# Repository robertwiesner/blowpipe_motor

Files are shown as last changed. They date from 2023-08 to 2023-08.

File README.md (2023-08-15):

# Glassblowing adapter

This project is to build a blow pipe adapter to help with solo blowing. In contras to the external compressor to the blowpie using a hose. 
The goals include
* Identic PCB for blowpipe and wireless controller
* Easy configurable
* Using Wifi or Bluetooth as communication between the remote control and blow piep adapter
* Measuring the set and create air pressure
* Worktime at last 4 hours on one charge
* Reasonable cost effective

I'm using a Rasperry Pi Pico W running Micropython.

The repository contains
* Schematics for the PCB
* FreeCAD 0.21 models with easy adjustments for the adapter and remote control

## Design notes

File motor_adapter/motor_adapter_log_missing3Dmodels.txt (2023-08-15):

Can not find model defined with enviroment variable:
${KICAD6_3DMODEL_USER_DIR}/RPi Pico W w_headers.step
Can not find model defined with enviroment variable:
${KICAD6_3DMODEL_DIR}/LED_SMD.3dshapes/LED_0603_1608Metric.wrl
Can not find model defined with enviroment variable:
${KICAD6_3DMODEL_DIR}/Resistor_SMD.3dshapes/R_0402_1005Metric.wrl
Can not find model defined with enviroment variable:
${KICAD6_3DMODEL_DIR}/Capacitor_Tantalum_SMD.3dshapes/CP_EIA-7343-31_Kemet-D.wrl
Can not find model defined with enviroment variable:
${KICAD6_3DMODEL_DIR}/Inductor_SMD.3dshapes/L_0603_1608Metric.wrl
Can not find model defined with enviroment variable:
${KICAD6_3DMODEL_DIR}/LED_SMD.3dshapes/LED_0603_1608Metric.wrl
Can not find model defined with enviroment variable:
${KICAD6_3DMODEL_DIR}/Resistor_SMD.3dshapes/R_0402_1005Metric.wrl
Can not find model defined with enviroment variable:
${KICAD6_3DMODEL_DIR}/Capacitor_SMD.3dshapes/C_0603_1608Metric.wrl
Can not find model defined with enviroment variable:
${KICAD6_3DMODEL_DIR}/Package_TO_SOT_SMD.3dshapes/SOT-223.wrl
Can not find model defined with enviroment variable:
${KICAD6_3DMODEL_DIR}/Capacitor_SMD.3dshapes/C_0402_1005Metric.wrl
Can not find model defined with enviroment variable:
${KICAD6_3DMODEL_DIR}/Capacitor_SMD.3dshapes/C_0402_1005Metric.wrl
Can not find model defined with enviroment variable:
${KICAD6_3DMODEL_DIR}/Resistor_SMD.3dshapes/R_0402_1005Metric.wrl
Can not find model defined with enviroment variable:
${KICAD6_3DMODEL_DIR}/Capacitor_SMD.3dshapes/CP_Elec_10x10.5.wrl
Can not find model defined with enviroment variable:
${KICAD6_3DMODEL_DIR}/Package_TO_SOT_SMD.3dshapes/TO-263-5_TabPin6.wrl
Can not find model defined with enviroment variable:
${KICAD6_3DMODEL_DIR}/Resistor_SMD.3dshapes/R_0402_1005Metric.wrl
Can not find model defined with enviroment variable:
${KICAD6_3DMODEL_DIR}/Capacitor_SMD.3dshapes/C_0402_1005Metric.wrl
Can not find model defined with enviroment variable:
${KICAD6_3DMODEL_DIR}/Capacitor_SMD.3dshapes/C_0603_1608Metric.wrl
Can not find model defined with enviroment variable:
${KICAD6_3DMODEL_DIR}/Capacitor_Tantalum_SMD.3dshapes/CP_EIA-3216-18_Kemet-A.wrl
Can not find model defined with enviroment variable:
${KICAD6_3DMODEL_DIR}/Capacitor_SMD.3dshapes/C_0402_1005Metric.wrl
Can not find model defined with enviroment variable:
${KICAD6_3DMODEL_DIR}/Capacitor_Tantalum_SMD.3dshapes/CP_EIA-3216-18_Kemet-A.wrl
Can not find model defined with enviroment variable:
${KICAD6_3DMODEL_DIR}/Connector_PinSocket_2.54mm.3dshapes/PinSocket_1x04_P2.54mm_Vertical.wrl
Can not find model defined with enviroment variable:
${KICAD6_3DMODEL_DIR}/Capacitor_SMD.3dshapes/C_0603_1608Metric.wrl
Can not find model defined with enviroment variable:
${KICAD6_3DMODEL_DIR}/Capacitor_SMD.3dshapes/C_0402_1005Metric.wrl
Can not find model defined with enviroment variable:
${KICAD6_3DMODEL_DIR}/Package_SO.3dshapes/TSSOP-10_3x3mm_P0.5mm.wrl
Can not find model defined with enviroment variable:
${KICAD6_3DMODEL_DIR}/Inductor_SMD.3dshapes/L_Bourns_SRP7028A_7.3x6.6mm.wrl
Can not find model defined with enviroment variable:
${KICAD6_3DMODEL_DIR}/Resistor_SMD.3dshapes/R_0402_1005Metric.wrl
Can not find model defined with enviroment variable:
${KICAD6_3DMODEL_DIR}/LED_SMD.3dshapes/LED_0603_1608Metric.wrl
Can not find model defined with enviroment variable:
${KICAD6_3DMODEL_DIR}/Capacitor_SMD.3dshapes/C_0402_1005Metric.wrl
Can not find model defined with enviroment variable:
${KICAD6_3DMODEL_DIR}/Connector_PinHeader_2.54mm.3dshapes/PinHeader_1x02_P2.54mm_Vertical.wrl
Can not find model defined with enviroment variable:
${KICAD6_3DMODEL_DIR}/Resistor_SMD.3dshapes/R_0402_1005Metric.wrl
Can not find model defined with enviroment variable:
${KICAD6_3DMODEL_DIR}/Button_Switch_SMD.3dshapes/SW_DIP_SPSTx04_Slide_Copal_CHS-04B_W7.62mm_P1.27mm.wrl
Can not find model defined with enviroment variable:
${KICAD6_3DMODEL_DIR}/Capacitor_SMD.3dshapes/C_0603_1608Metric.wrl
Can not find model defined with enviroment variable:
${KICAD6_3DMODEL_DIR}/Connector_PinHeader_2.54mm.3dshapes/PinHeader_1x05_P2.54mm_Vertical.wrl
Can not find model defined with enviroment variable:
${KICAD6_3DMODEL_DIR}/LED_SMD.3dshapes/LED_0603_1608Metric.wrl
Can not find model defined with enviroment variable:
${KICAD6_3DMODEL_DIR}/Capacitor_SMD.3dshapes/C_0402_1005Metric.wrl
Can not find model defined with enviroment variable:
${KICAD6_3DMODEL_DIR}/Connector_PinHeader_2.54mm.3dshapes/PinHeader_1x03_P2.54mm_Vertical.wrl
Can not find model defined with enviroment variable:
${KICAD6_3DMODEL_DIR}/Resistor_SMD.3dshapes/R_0402_1005Metric.wrl
Can not find model defined with enviroment variable:
${KICAD6_3DMODEL_DIR}/Resistor_SMD.3dshapes/R_0402_1005Metric.wrl
Can not find model defined with enviroment variable:
${KICAD6_3DMODEL_DIR}/Resistor_SMD.3dshapes/R_0402_1005Metric.wrl
Can not find model defined with enviroment variable:
${KICAD6_3DMODEL_DIR}/Inductor_SMD.3dshapes/L_Bourns_SRP7028A_7.3x6.6mm.wrl
[('A101', '${KICAD6_3DMODEL_USER_DIR}/RPi Pico W w_headers.step'), ('D404', '${KICAD6_3DMODEL_DIR}/LED_SMD.3dshapes/LED_0603_1608Metric.wrl'), ('R503', '${KICAD6_3DMODEL_DIR}/Resistor_SMD.3dshapes/R_0402_1005Metric.wrl'), ('C302', '${KICAD6_3DMODEL_DIR}/Capacitor_Tantalum_SMD.3dshapes/CP_EIA-7343-31_Kemet-D.wrl'), ('FB301', '${KICAD6_3DMODEL_DIR}/Inductor_SMD.3dshapes/L_0603_1608Metric.wrl'), ('D403', '${KICAD6_3DMODEL_DIR}/LED_SMD.3dshapes/LED_0603_1608Metric.wrl'), ('R501', '${KICAD6_3DMODEL_DIR}/Resistor_SMD.3dshapes/R_0402_1005Metric.wrl'), ('C305', '${KICAD6_3DMODEL_DIR}/Capacitor_SMD.3dshapes/C_0603_1608Metric.wrl'), ('U302', '${KICAD6_3DMODEL_DIR}/Package_TO_SOT_SMD.3dshapes/SOT-223.wrl'), ('C402', '${KICAD6_3DMODEL_DIR}/Capacitor_SMD.3dshapes/C_0402_1005Metric.wrl'), ('C201', '${KICAD6_3DMODEL_DIR}/Capacitor_SMD.3dshapes/C_0402_1005Metric.wrl'), ('R404', '${KICAD6_3DMODEL_DIR}/Resistor_SMD.3dshapes/R_0402_1005Metric.wrl'), ('C301', '${KICAD6_3DMODEL_DIR}/Capacitor_SMD.3dshapes/CP_Elec_10x10.5.wrl'), ('U301', '${KICAD6_3DMODEL_DIR}/Package_TO_SOT_SMD.3dshapes/TO-263-5_TabPin6.wrl'), ('R502', '${KICAD6_3DMODEL_DIR}/Resistor_SMD.3dshapes/R_0402_1005Metric.wrl'), ('C401', '${KICAD6_3DMODEL_DIR}/Capacitor_SMD.3dshapes/C_0402_1005Metric.wrl'), ('C306', '${KICAD6_3DMODEL_DIR}/Capacitor_SMD.3dshapes/C_0603_1608Metric.wrl'), ('C403', '${KICAD6_3DMODEL_DIR}/Capacitor_Tantalum_SMD.3dshapes/CP_EIA-3216-18_Kemet-A.wrl'), ('C307', '${KICAD6_3DMODEL_DIR}/Capacitor_SMD.3dshapes/C_0402_1005Metric.wrl'), ('C404', '${KICAD6_3DMODEL_DIR}/Capacitor_Tantalum_SMD.3dshapes/CP_EIA-3216-18_Kemet-A.wrl'), ('J102', '${KICAD6_3DMODEL_DIR}/Connector_PinSocket_2.54mm.3dshapes/PinSocket_1x04_P2.54mm_Vertical.wrl'), ('C303', '${KICAD6_3DMODEL_DIR}/Capacitor_SMD.3dshapes/C_0603_1608Metric.wrl'), ('C501', '${KICAD6_3DMODEL_DIR}/Capacitor_SMD.3dshapes/C_0402_1005Metric.wrl'), ('U501', '${KICAD6_3DMODEL_DIR}/Package_SO.3dshapes/TSSOP-10_3x3mm_P0.5mm.wrl'), ('L301', '${KICAD6_3DMODEL_DIR}/Inductor_SMD.3dshapes/L_Bourns_SRP7028A_7.3x6.6mm.wrl'), ('R101', '${KICAD6_3DMODEL_DIR}/Resistor_SMD.3dshapes/R_0402_1005Metric.wrl'), ('D402', '${KICAD6_3DMODEL_DIR}/LED_SMD.3dshapes/LED_0603_1608Metric.wrl'), ('C308', '${KICAD6_3DMODEL_DIR}/Capacitor_SMD.3dshapes/C_0402_1005Metric.wrl'), ('J302', '${KICAD6_3DMODEL_DIR}/Connector_PinHeader_2.54mm.3dshapes/PinHeader_1x02_P2.54mm_Vertical.wrl'), ('R403', '${KICAD6_3DMODEL_DIR}/Resistor_SMD.3dshapes/R_0402_1005Metric.wrl'), ('SW101', '${KICAD6_3DMODEL_DIR}/Button_Switch_SMD.3dshapes/SW_DIP_SPSTx04_Slide_Copal_CHS-04B_W7.62mm_P1.27mm.wrl'), ('C304', '${KICAD6_3DMODEL_DIR}/Capacitor_SMD.3dshapes/C_0603_1608Metric.wrl'), ('J101', '${KICAD6_3DMODEL_DIR}/Connector_PinHeader_2.54mm.3dshapes/PinHeader_1x05_P2.54mm_Vertical.wrl'), ('D401', '${KICAD6_3DMODEL_DIR}/LED_SMD.3dshapes/LED_0603_1608Metric.wrl'), ('C309', '${KICAD6_3DMODEL_DIR}/Capacitor_SMD.3dshapes/C_0402_1005Metric.wrl'), ('J402', '${KICAD6_3DMODEL_DIR}/Connector_PinHeader_2.54mm.3dshapes/PinHeader_1x03_P2.54mm_Vertical.wrl'), ('R402', '${KICAD6_3DMODEL_DIR}/Resistor_SMD.3dshapes/R_0402_1005Metric.wrl'), ('R401', '${KICAD6_3DMODEL_DIR}/Resistor_SMD.3dshapes/R_0402_1005Metric.wrl'), ('R102', '${KICAD6_3DMODEL_DIR}/Resistor_SMD.3dshapes/R_0402_1005Metric.wrl'), ('L302', '${KICAD6_3DMODEL_DIR}/Inductor_SMD.3dshapes/L_Bourns_SRP7028A_7.3x6.6mm.wrl')]

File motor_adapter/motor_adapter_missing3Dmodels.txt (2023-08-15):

### Missing 3D models - created on 2023-07-03 17:45
### Printed by checking_3D_models plugin
Board file: /home/robert/kicad/motor_adapter/motor_adapter.kicad_pcb
3D missing models written to:
/home/robert/kicad/motor_adapter/motor_adapter_missing3Dmodels.txt
-------
('A101', '${KICAD6_3DMODEL_USER_DIR}/RPi Pico W w_headers.step')
('D404', '${KICAD6_3DMODEL_DIR}/LED_SMD.3dshapes/LED_0603_1608Metric.wrl')
('R503', '${KICAD6_3DMODEL_DIR}/Resistor_SMD.3dshapes/R_0402_1005Metric.wrl')
('C302', '${KICAD6_3DMODEL_DIR}/Capacitor_Tantalum_SMD.3dshapes/CP_EIA-7343-31_Kemet-D.wrl')
('FB301', '${KICAD6_3DMODEL_DIR}/Inductor_SMD.3dshapes/L_0603_1608Metric.wrl')
('D403', '${KICAD6_3DMODEL_DIR}/LED_SMD.3dshapes/LED_0603_1608Metric.wrl')
('R501', '${KICAD6_3DMODEL_DIR}/Resistor_SMD.3dshapes/R_0402_1005Metric.wrl')
('C305', '${KICAD6_3DMODEL_DIR}/Capacitor_SMD.3dshapes/C_0603_1608Metric.wrl')
('U302', '${KICAD6_3DMODEL_DIR}/Package_TO_SOT_SMD.3dshapes/SOT-223.wrl')
('C402', '${KICAD6_3DMODEL_DIR}/Capacitor_SMD.3dshapes/C_0402_1005Metric.wrl')
('C201', '${KICAD6_3DMODEL_DIR}/Capacitor_SMD.3dshapes/C_0402_1005Metric.wrl')
('R404', '${KICAD6_3DMODEL_DIR}/Resistor_SMD.3dshapes/R_0402_1005Metric.wrl')
('C301', '${KICAD6_3DMODEL_DIR}/Capacitor_SMD.3dshapes/CP_Elec_10x10.5.wrl')
('U301', '${KICAD6_3DMODEL_DIR}/Package_TO_SOT_SMD.3dshapes/TO-263-5_TabPin6.wrl')
('R502', '${KICAD6_3DMODEL_DIR}/Resistor_SMD.3dshapes/R_0402_1005Metric.wrl')
('C401', '${KICAD6_3DMODEL_DIR}/Capacitor_SMD.3dshapes/C_0402_1005Metric.wrl')
('C306', '${KICAD6_3DMODEL_DIR}/Capacitor_SMD.3dshapes/C_0603_1608Metric.wrl')
('C403', '${KICAD6_3DMODEL_DIR}/Capacitor_Tantalum_SMD.3dshapes/CP_EIA-3216-18_Kemet-A.wrl')
('C307', '${KICAD6_3DMODEL_DIR}/Capacitor_SMD.3dshapes/C_0402_1005Metric.wrl')
('C404', '${KICAD6_3DMODEL_DIR}/Capacitor_Tantalum_SMD.3dshapes/CP_EIA-3216-18_Kemet-A.wrl')
('J102', '${KICAD6_3DMODEL_DIR}/Connector_PinSocket_2.54mm.3dshapes/PinSocket_1x04_P2.54mm_Vertical.wrl')
('C303', '${KICAD6_3DMODEL_DIR}/Capacitor_SMD.3dshapes/C_0603_1608Metric.wrl')
('C501', '${KICAD6_3DMODEL_DIR}/Capacitor_SMD.3dshapes/C_0402_1005Metric.wrl')
('U501', '${KICAD6_3DMODEL_DIR}/Package_SO.3dshapes/TSSOP-10_3x3mm_P0.5mm.wrl')
('L301', '${KICAD6_3DMODEL_DIR}/Inductor_SMD.3dshapes/L_Bourns_SRP7028A_7.3x6.6mm.wrl')
('R101', '${KICAD6_3DMODEL_DIR}/Resistor_SMD.3dshapes/R_0402_1005Metric.wrl')
('D402', '${KICAD6_3DMODEL_DIR}/LED_SMD.3dshapes/LED_0603_1608Metric.wrl')
('C308', '${KICAD6_3DMODEL_DIR}/Capacitor_SMD.3dshapes/C_0402_1005Metric.wrl')
('J302', '${KICAD6_3DMODEL_DIR}/Connector_PinHeader_2.54mm.3dshapes/PinHeader_1x02_P2.54mm_Vertical.wrl')
('R403', '${KICAD6_3DMODEL_DIR}/Resistor_SMD.3dshapes/R_0402_1005Metric.wrl')
('SW101', '${KICAD6_3DMODEL_DIR}/Button_Switch_SMD.3dshapes/SW_DIP_SPSTx04_Slide_Copal_CHS-04B_W7.62mm_P1.27mm.wrl')
('C304', '${KICAD6_3DMODEL_DIR}/Capacitor_SMD.3dshapes/C_0603_1608Metric.wrl')
('J101', '${KICAD6_3DMODEL_DIR}/Connector_PinHeader_2.54mm.3dshapes/PinHeader_1x05_P2.54mm_Vertical.wrl')
('D401', '${KICAD6_3DMODEL_DIR}/LED_SMD.3dshapes/LED_0603_1608Metric.wrl')
('C309', '${KICAD6_3DMODEL_DIR}/Capacitor_SMD.3dshapes/C_0402_1005Metric.wrl')
('J402', '${KICAD6_3DMODEL_DIR}/Connector_PinHeader_2.54mm.3dshapes/PinHeader_1x03_P2.54mm_Vertical.wrl')
('R402', '${KICAD6_3DMODEL_DIR}/Resistor_SMD.3dshapes/R_0402_1005Metric.wrl')
('R401', '${KICAD6_3DMODEL_DIR}/Resistor_SMD.3dshapes/R_0402_1005Metric.wrl')
('R102', '${KICAD6_3DMODEL_DIR}/Resistor_SMD.3dshapes/R_0402_1005Metric.wrl')
('L302', '${KICAD6_3DMODEL_DIR}/Inductor_SMD.3dshapes/L_Bourns_SRP7028A_7.3x6.6mm.wrl')
-------
NUM of 3D missing models:40
checked extensions ['.stp', '.step', '.stpZ']

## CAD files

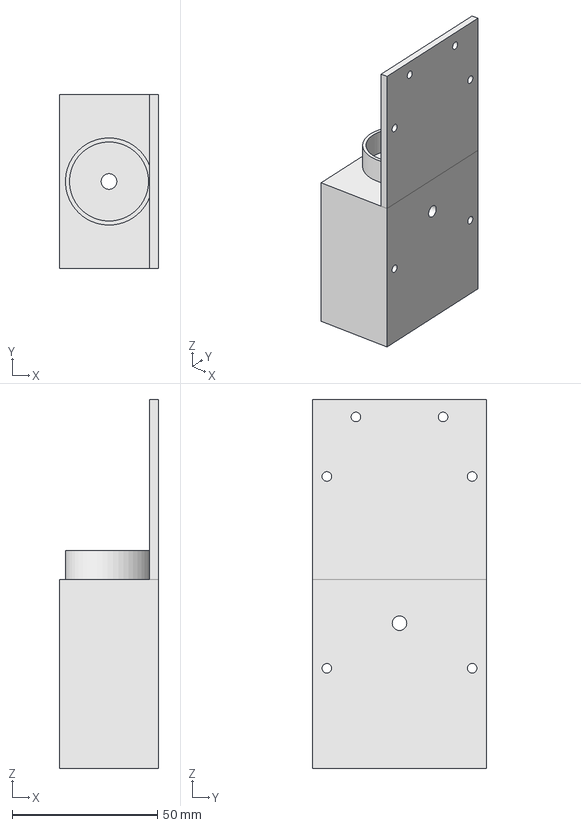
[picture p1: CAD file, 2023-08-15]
freecad/blowpipe_adapter.FCStd
34.0 x 60.0 x 127.0 mm

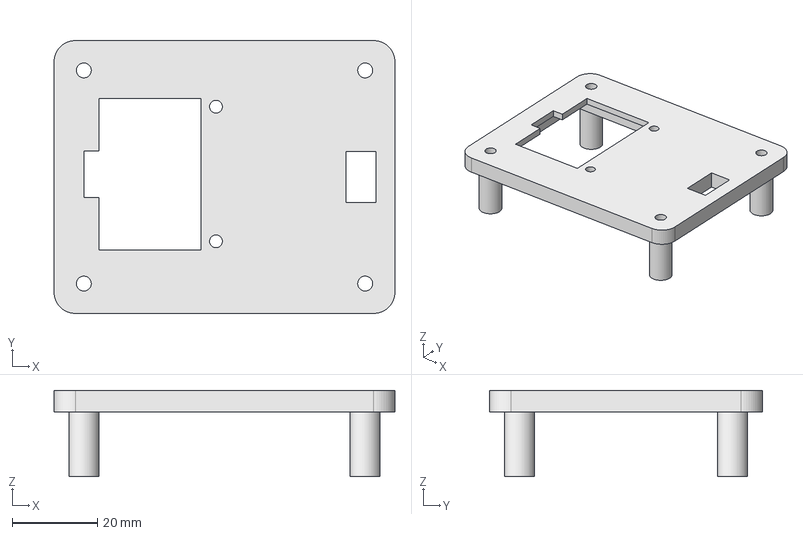
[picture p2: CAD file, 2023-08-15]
freecad/pcb_box_top.FCStd
80.0 x 64.0 x 20.2 mm

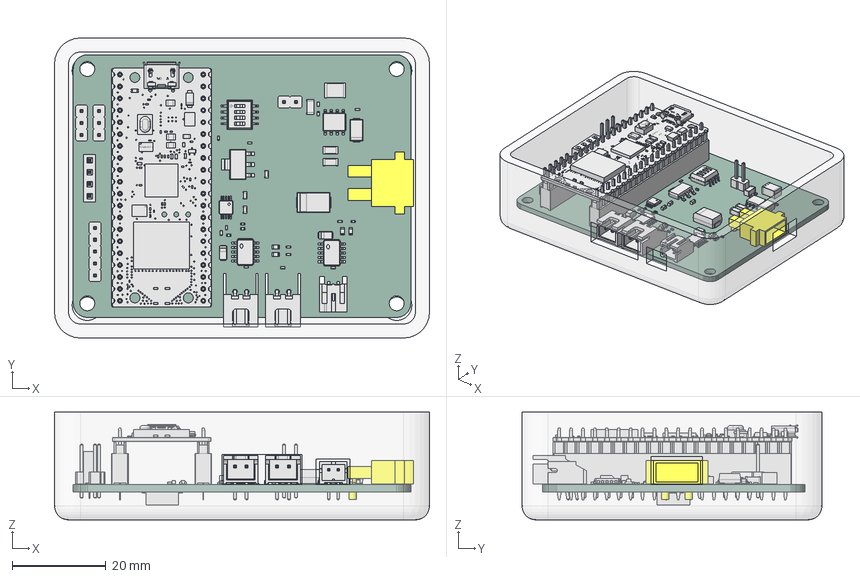
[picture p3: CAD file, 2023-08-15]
freecad/pcb_box.FCStd
80.0 x 64.0 x 23.0 mm
_autosave-motor_adapter PCB

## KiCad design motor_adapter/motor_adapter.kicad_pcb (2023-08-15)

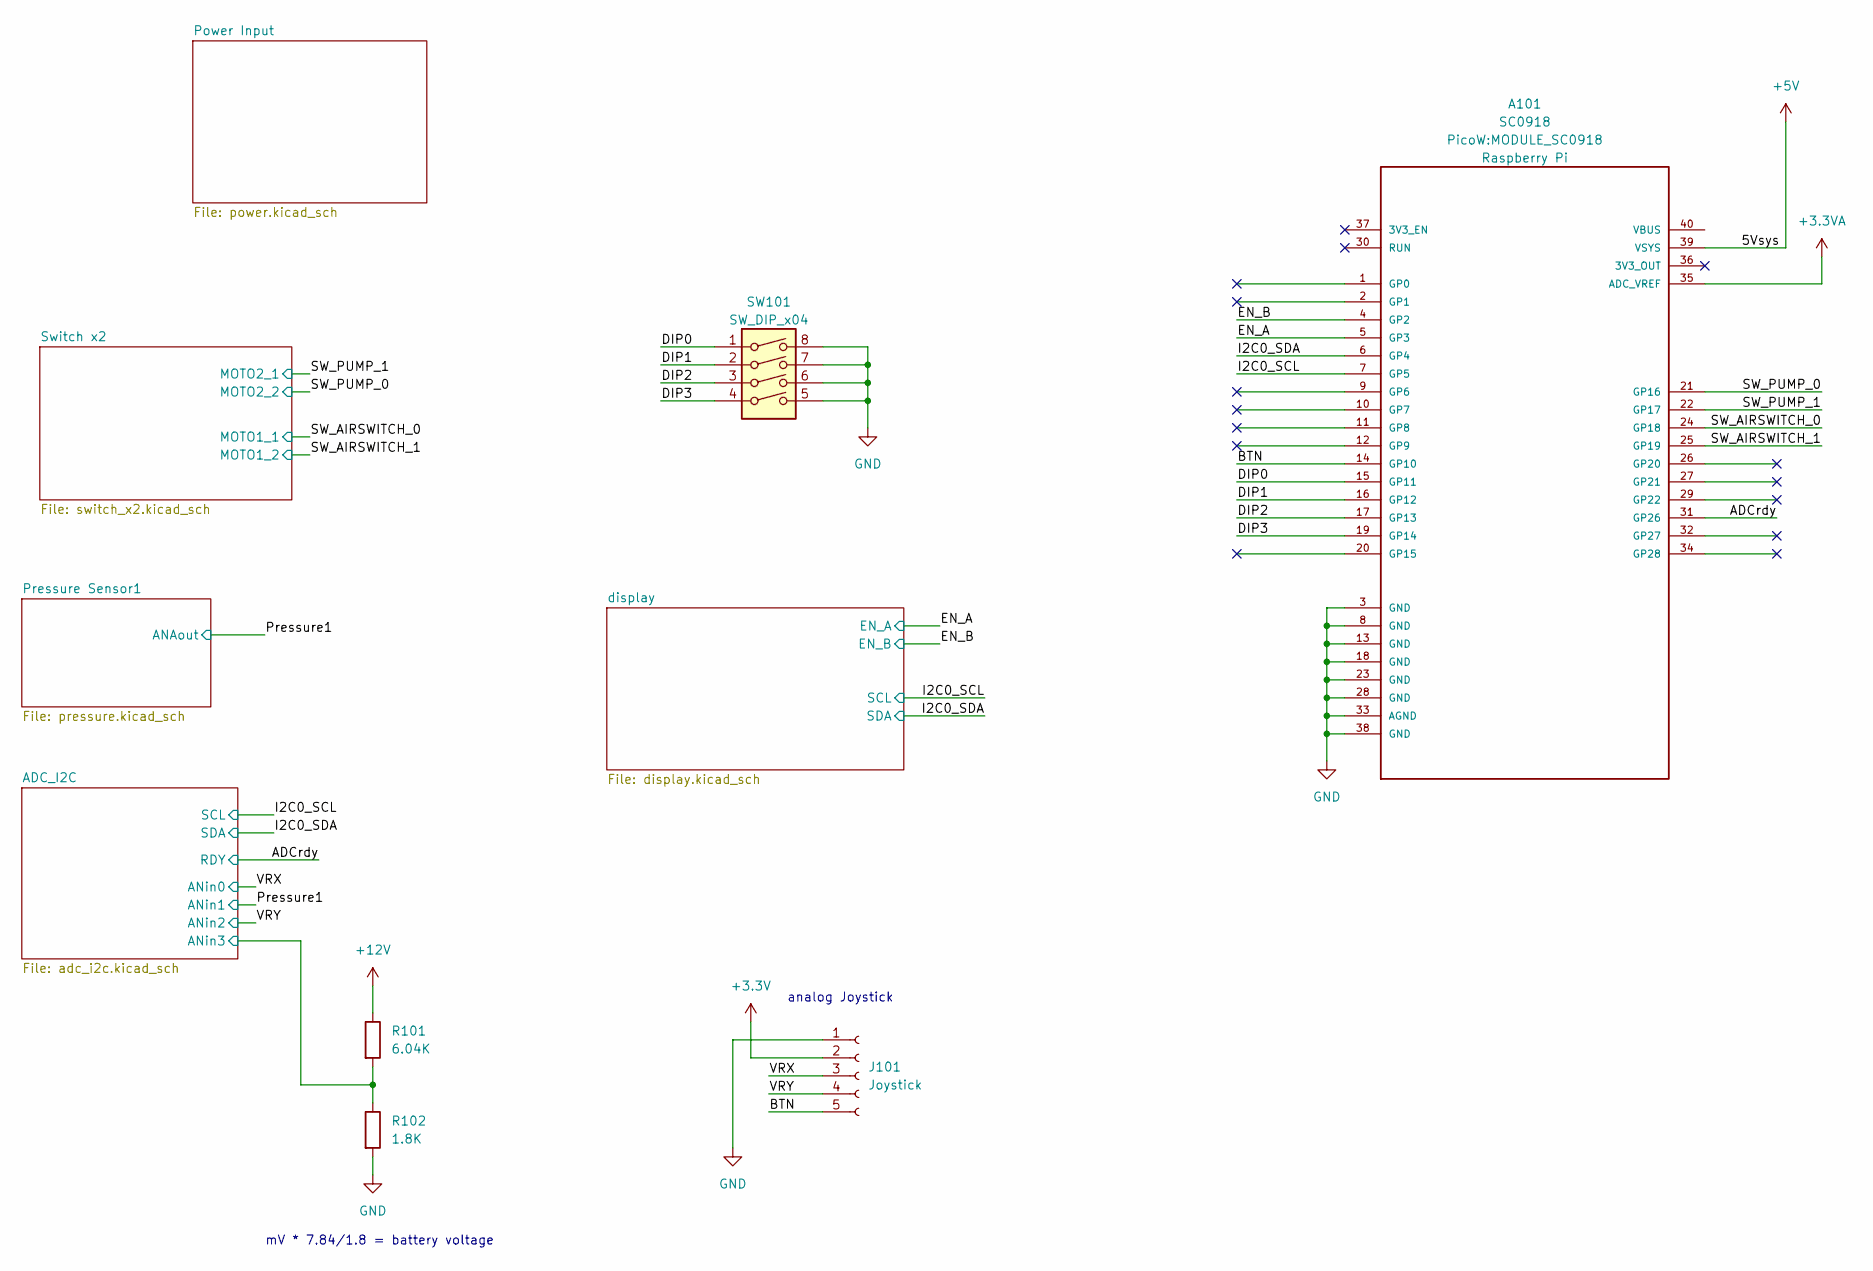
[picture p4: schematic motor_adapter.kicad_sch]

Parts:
A101: SC0918; MODULE_SC0918; PARTREV 1.6
J101: Joystick; PinHeader_1x05_P2.54mm_Vertical
R101: 6.04K; R_0402_1005Metric; Part 0402WGF2001TCE; LCSC C852895
R102: 1.8K; R_0402_1005Metric; Part 0402WGF2001TCE; LCSC C852621
SW101: SW_DIP_x04; SW_DIP_SPSTx04_Slide_Copal_CHS-04B_W7.62mm_P1.27mm; LCSC C845385

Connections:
+3.3V: J101.2; also elsewhere on the board
+3.3VA: A101.35 (ADC_VREF); also elsewhere on the board
/ADC_I2C/ANin3: R101.2, R102.1; also elsewhere on the board
/ADCrdy: A101.31 (GP26); also elsewhere on the board
/BTN: A101.14 (GP10), J101.5
/DIP0: A101.15 (GP11), SW101.1
/DIP1: A101.16 (GP12), SW101.2
/DIP2: A101.17 (GP13), SW101.3
/DIP3: A101.19 (GP14), SW101.4
/EN_A: A101.5 (GP3)
/EN_B: A101.4 (GP2)
/I2C0_SCL: A101.7 (GP5); also elsewhere on the board
/I2C0_SDA: A101.6 (GP4); also elsewhere on the board
/SW_AIRSWITCH_0: A101.24 (GP18); also elsewhere on the board
/SW_AIRSWITCH_1: A101.25 (GP19); also elsewhere on the board
/SW_PUMP_0: A101.21 (GP16); also elsewhere on the board
/SW_PUMP_1: A101.22 (GP17); also elsewhere on the board
/VRX: J101.3; also elsewhere on the board
/VRY: J101.4; also elsewhere on the board
GND: A101.3 (GND), A101.8 (GND), A101.13 (GND), A101.18 (GND), A101.23 (GND), A101.28 (GND), A101.33 (AGND), A101.38 (GND), J101.1, R102.2, SW101.5, SW101.6, SW101.7, SW101.8; also elsewhere on the board

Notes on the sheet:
mV * 7.84/1.8 = battery voltage
analog Joystick

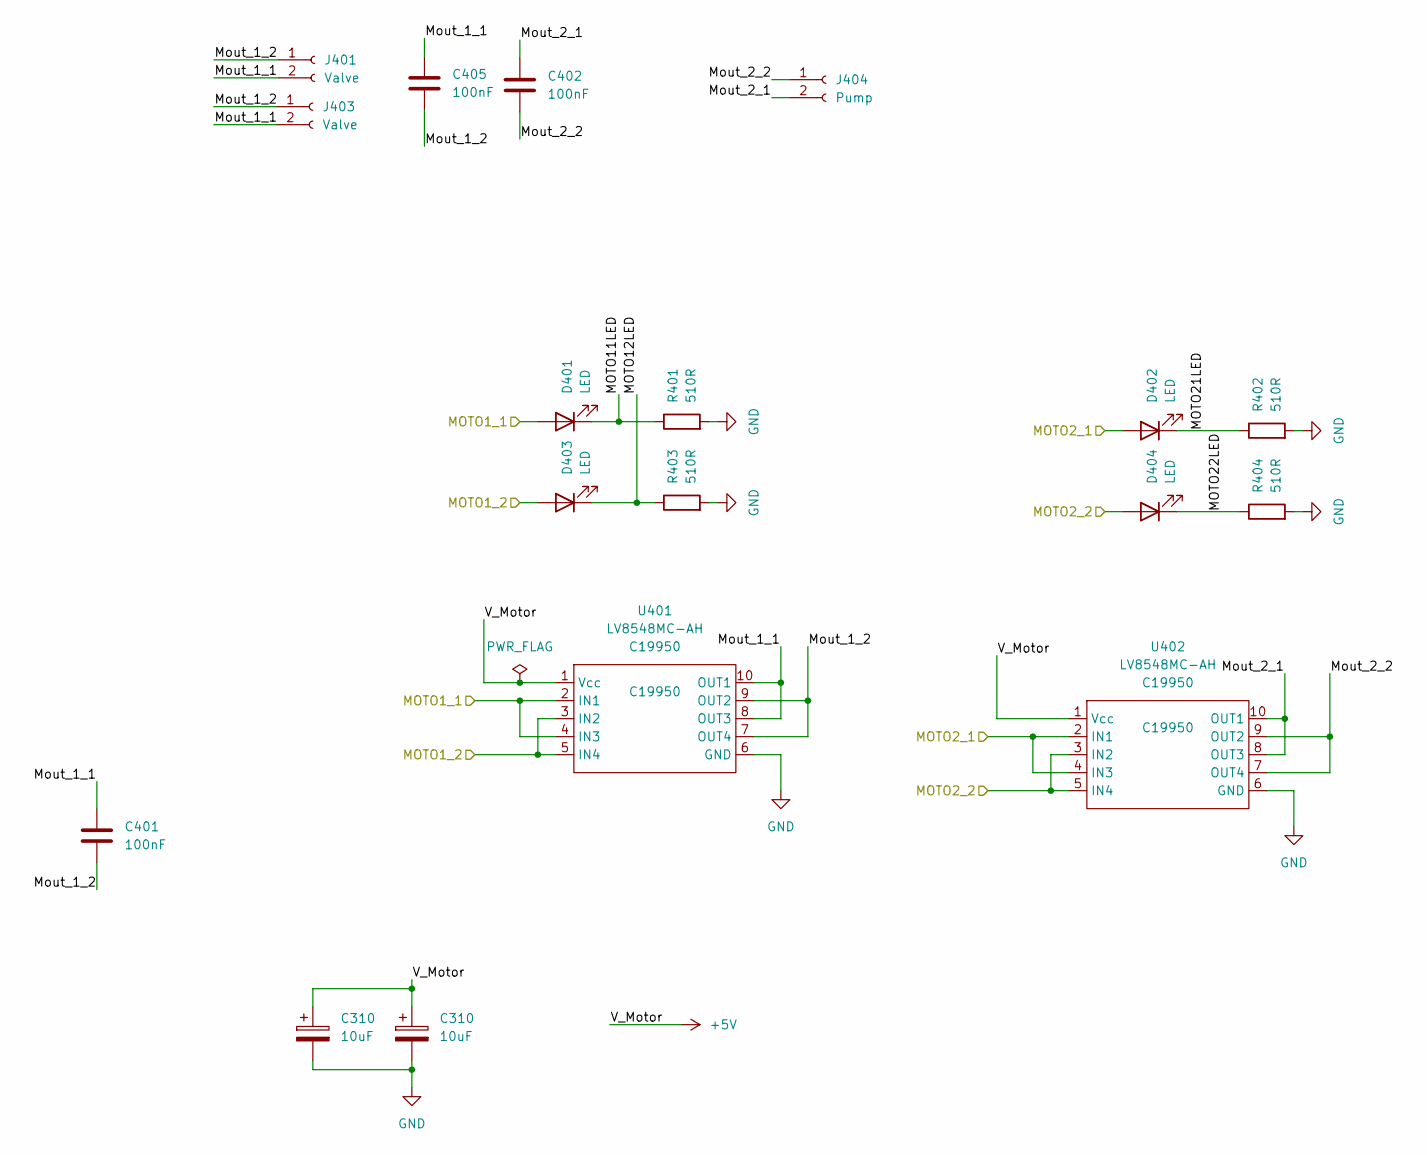
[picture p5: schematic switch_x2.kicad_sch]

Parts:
C310: 10uF; CP_EIA-3216-18_Kemet-A; LCSC C128254
C401, C402, C405: 100nF; C_0402_1005Metric; Part CL05B104KO5NNNC; LCSC C1525
D401, D402, D403, D404: LED; LED_0603_1608Metric; LCSC C72043
J401, J403: Valve; JST_XH_S2B-XH-A-1_1x02_P2.50mm_Horizontal
J404: Pump; JST_PH_S2B-PH-SM4-TB_1x02-1MP_P2.00mm_Horizontal
R401, R402, R403, R404: 510R; R_0402_1005Metric; LCSC C25123
U401, U402: LV8548MC-AH; SOIC-10-1mm; LCSC C19950

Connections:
/SW_AIRSWITCH_0: D401.2 (A), U401.2 (IN1), U401.4 (IN3); also elsewhere on the board
/SW_AIRSWITCH_1: D403.2 (A), U401.3 (IN2), U401.5 (IN4); also elsewhere on the board
/SW_PUMP_0: D404.2 (A), U402.3 (IN2), U402.5 (IN4); also elsewhere on the board
/SW_PUMP_1: D402.2 (A), U402.2 (IN1), U402.4 (IN3); also elsewhere on the board
/Switch x2/MOTO11LED: D401.1 (K), R401.1
/Switch x2/MOTO12LED: D403.1 (K), R403.1
/Switch x2/MOTO21LED: D402.1 (K), R402.1
/Switch x2/MOTO22LED: D404.1 (K), R404.1
/Switch x2/Mout_1_1: C401.1, C405.1, J401.2, J403.2, U401.8 (OUT3), U401.10 (OUT1)
/Switch x2/Mout_1_2: C401.2, C405.2, J401.1, J403.1, U401.7 (OUT4), U401.9 (OUT2)
/Switch x2/Mout_2_1: C402.1, J404.2, U402.8 (OUT3), U402.10 (OUT1)
/Switch x2/Mout_2_2: C402.2, J404.1, U402.7 (OUT4), U402.9 (OUT2)
GND: C310.2, R401.2, R402.2, R403.2, R404.2, U401.6 (GND), U402.6 (GND); also elsewhere on the board

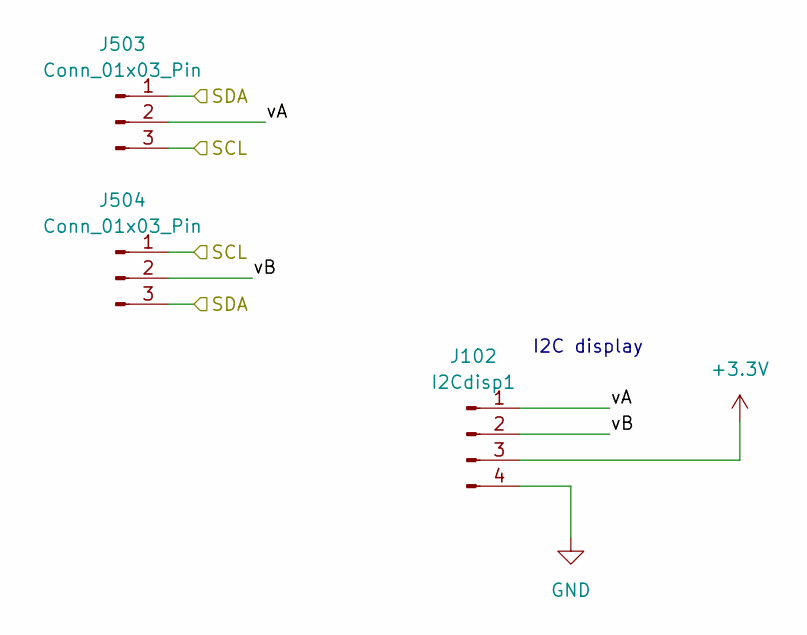
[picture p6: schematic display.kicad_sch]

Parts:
J102: I2Cdisp1; PinSocket_1x04_P2.54mm_Vertical
J503, J504: Conn_01x03_Pin; PinHeader_1x03_P2.54mm_Vertical

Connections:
/I2C0_SCL: J503.3, J504.1; also elsewhere on the board
/I2C0_SDA: J503.1, J504.3; also elsewhere on the board
/display/vA: J503.2; also elsewhere on the board
/display/vB: J504.2; also elsewhere on the board

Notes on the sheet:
I2C display

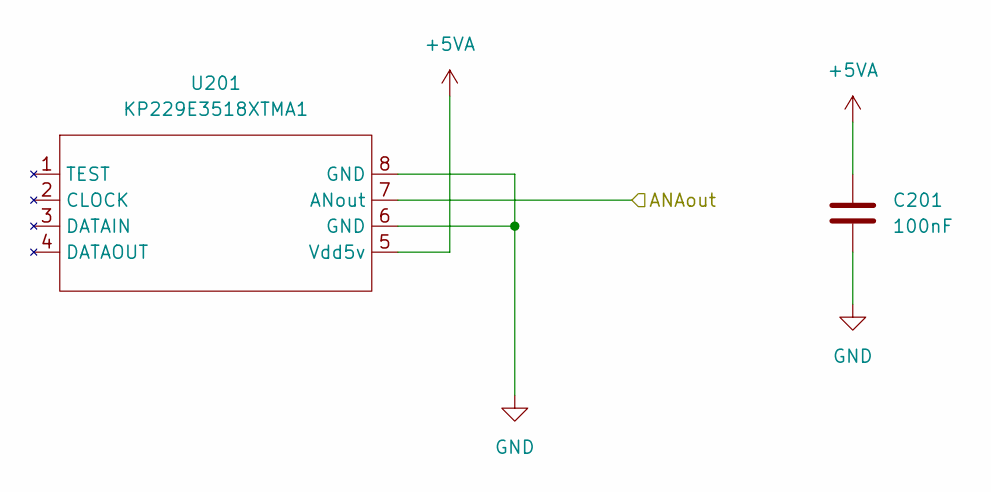
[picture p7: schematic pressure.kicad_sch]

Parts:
C201: 100nF; C_0402_1005Metric; Part CL05B104KO5NNNC; LCSC C1525
U201: KP229E3518XTMA1; PG-DSOF-8-16

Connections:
+5VA: C201.1, U201.5 (Vdd5v); also elsewhere on the board
/Pressure1: U201.7 (ANout); also elsewhere on the board
GND: C201.2, U201.6 (GND), U201.8 (GND); also elsewhere on the board

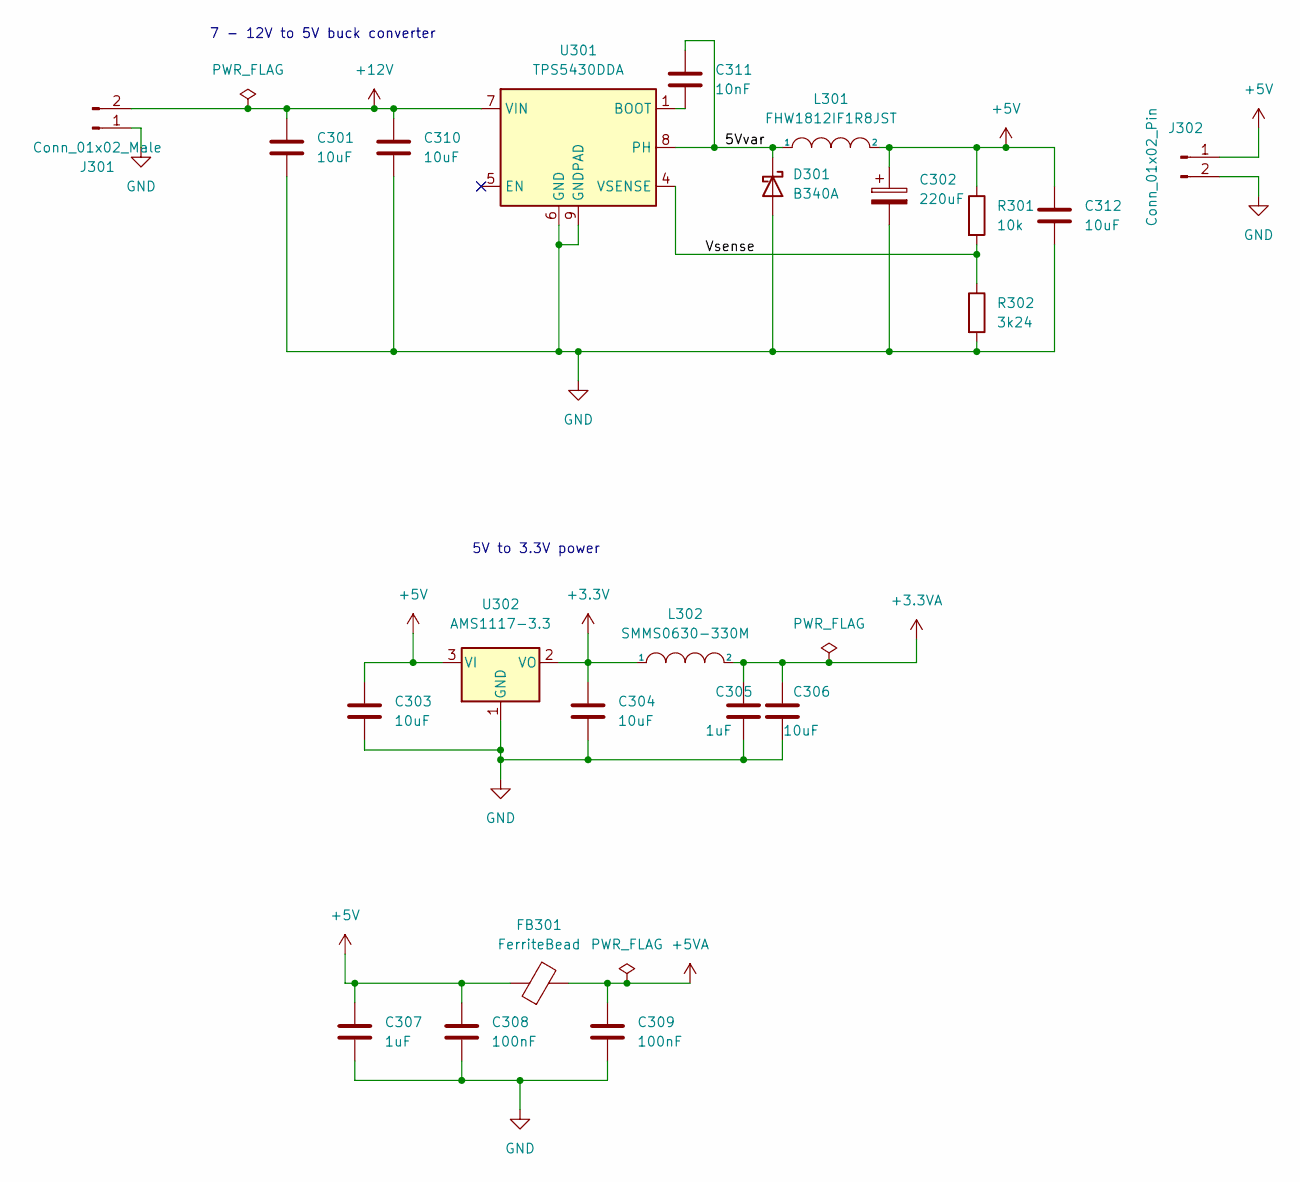
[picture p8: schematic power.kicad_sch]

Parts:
C301, C310, C312: 10uF; C_1206_3216Metric; LCSC C128855
C302: 220uF; CP_EIA-7343-31_Kemet-D; LCSC C8024
C303, C304, C306: 10uF; C_0603_1608Metric; LCSC C18800
C305: 1uF; C_0603_1608Metric; LCSC C92848
C307: 1uF; C_0402_1005Metric; LCSC C106254
C308, C309: 100nF; C_0402_1005Metric; LCSC C110251
C311: 10nF; C_0402_1005Metric; LCSC C2840480
D301: B340A; D_SMA; LCSC C3018525
FB301: FerriteBead; L_0603_1608Metric; LCSC C62708
J301: Conn_01x02_Male; AMASS_XT30U-F_1x02_P5.0mm_Vertical
J302: Conn_01x02_Pin; PinHeader_1x02_P2.54mm_Vertical
L301: FHW1812IF1R8JST; L_1812_4532Metric; LCSC C394113
L302: SMMS0630-330M; L_Bourns_SRP7028A_7.3x6.6mm; LCSC C149577
R301: 10k; R_0402_1005Metric; LCSC C60490
R302: 3k24; R_0402_1005Metric; LCSC C327346
U301: TPS5430DDA; TI_SO-PowerPAD-8_ThermalVias; LCSC C9864
U302: AMS1117-3.3; SOT-223; LCSC C347222

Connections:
+3.3V: C304.1, L302.1, U302.2 (VO); also elsewhere on the board
+3.3VA: C305.1, C306.1, L302.2; also elsewhere on the board
+5VA: C309.1, FB301.2; also elsewhere on the board
/Power Input/5Vvar: C311.2, D301.1 (K), L301.1, U301.8 (PH)
/Power Input/Vsense: R301.2, R302.1, U301.4 (VSENSE)
GND: C301.2, C302.2, C303.2, C304.2, C305.2, C306.2, C307.2, C308.2, C309.2, C310.2, C312.2, D301.2 (A), J301.1, J302.2, R302.2, U301.6 (GND), U301.9 (GNDPAD), U302.1 (GND); also elsewhere on the board
unnamed: C311.1, U301.1 (BOOT)

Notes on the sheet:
7 - 12V to 5V buck converter
5V to 3.3V power

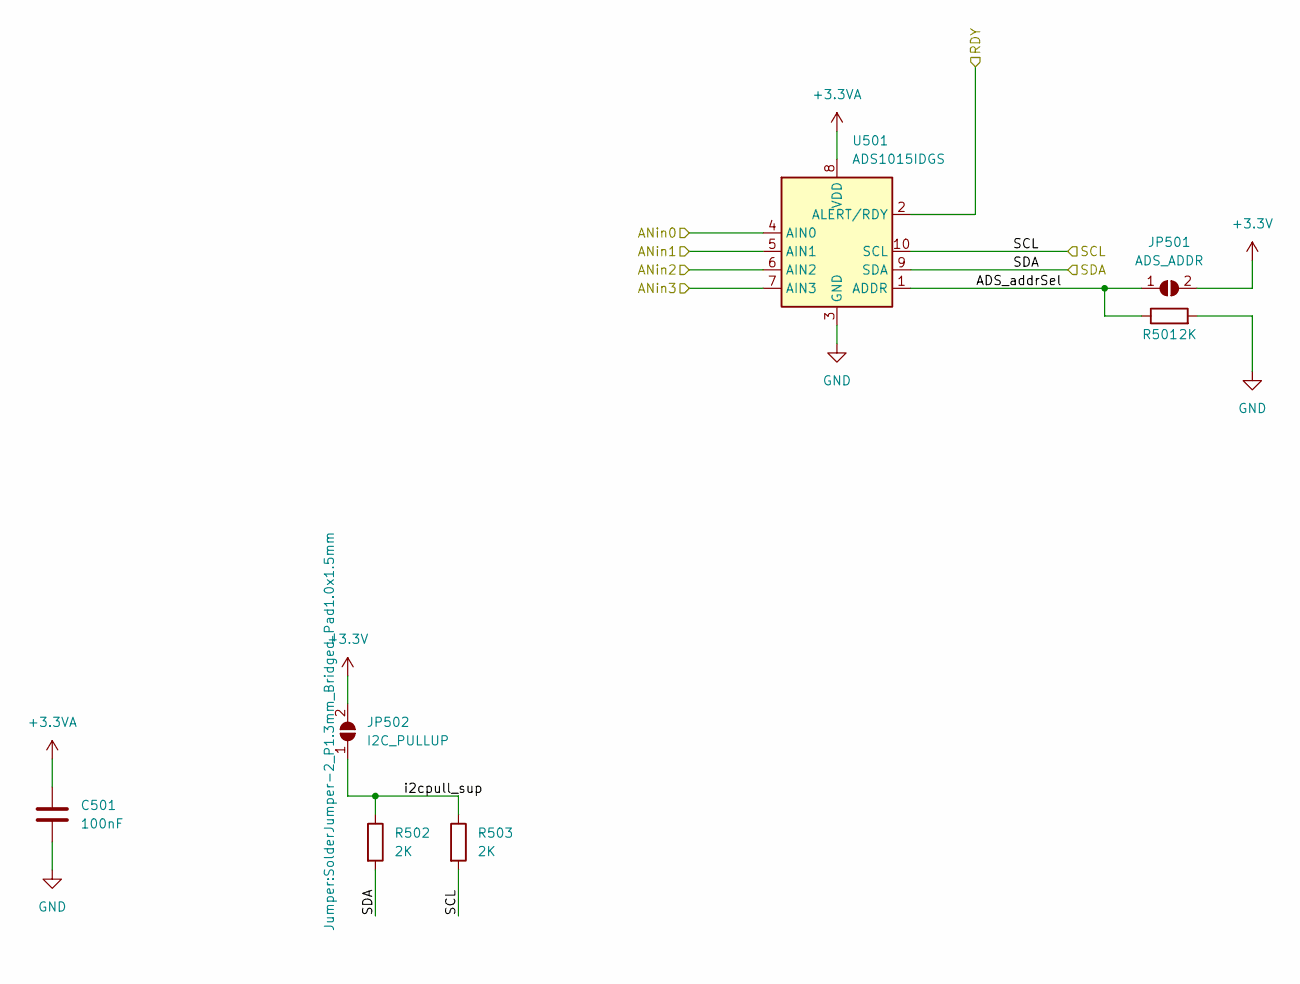
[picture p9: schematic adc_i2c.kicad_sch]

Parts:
C501: 100nF; C_0402_1005Metric; Part CL05B104KO5NNNC; LCSC C1525
JP501: ADS_ADDR; SolderJumper-2_P1.3mm_Open_RoundedPad1.0x1.5mm
JP502: I2C_PULLUP; SolderJumper-2_P1.3mm_Bridged_Pad1.0x1.5mm
R501, R502, R503: 2K; R_0402_1005Metric; Part 0402WGF2001TCE; LCSC C4109
U501: ADS1015IDGS; TSSOP-10_3x3mm_P0.5mm; LCSC C193969

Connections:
+3.3V: JP501.2 (B), JP502.2 (B); also elsewhere on the board
+3.3VA: C501.1, U501.8 (VDD); also elsewhere on the board
/ADC_I2C/ADS_addrSel: JP501.1 (A), R501.1, U501.1 (ADDR)
/ADC_I2C/ANin3: U501.7 (AIN3); also elsewhere on the board
/ADC_I2C/i2cpull_sup: JP502.1 (A), R502.1, R503.1
/ADCrdy: U501.2 (ALERT/RDY); also elsewhere on the board
/I2C0_SCL: R503.2, U501.10 (SCL); also elsewhere on the board
/I2C0_SDA: R502.2, U501.9 (SDA); also elsewhere on the board
/Pressure1: U501.5 (AIN1); also elsewhere on the board
/VRX: U501.4 (AIN0); also elsewhere on the board
/VRY: U501.6 (AIN2); also elsewhere on the board
GND: C501.2, R501.2, U501.3 (GND); also elsewhere on the board

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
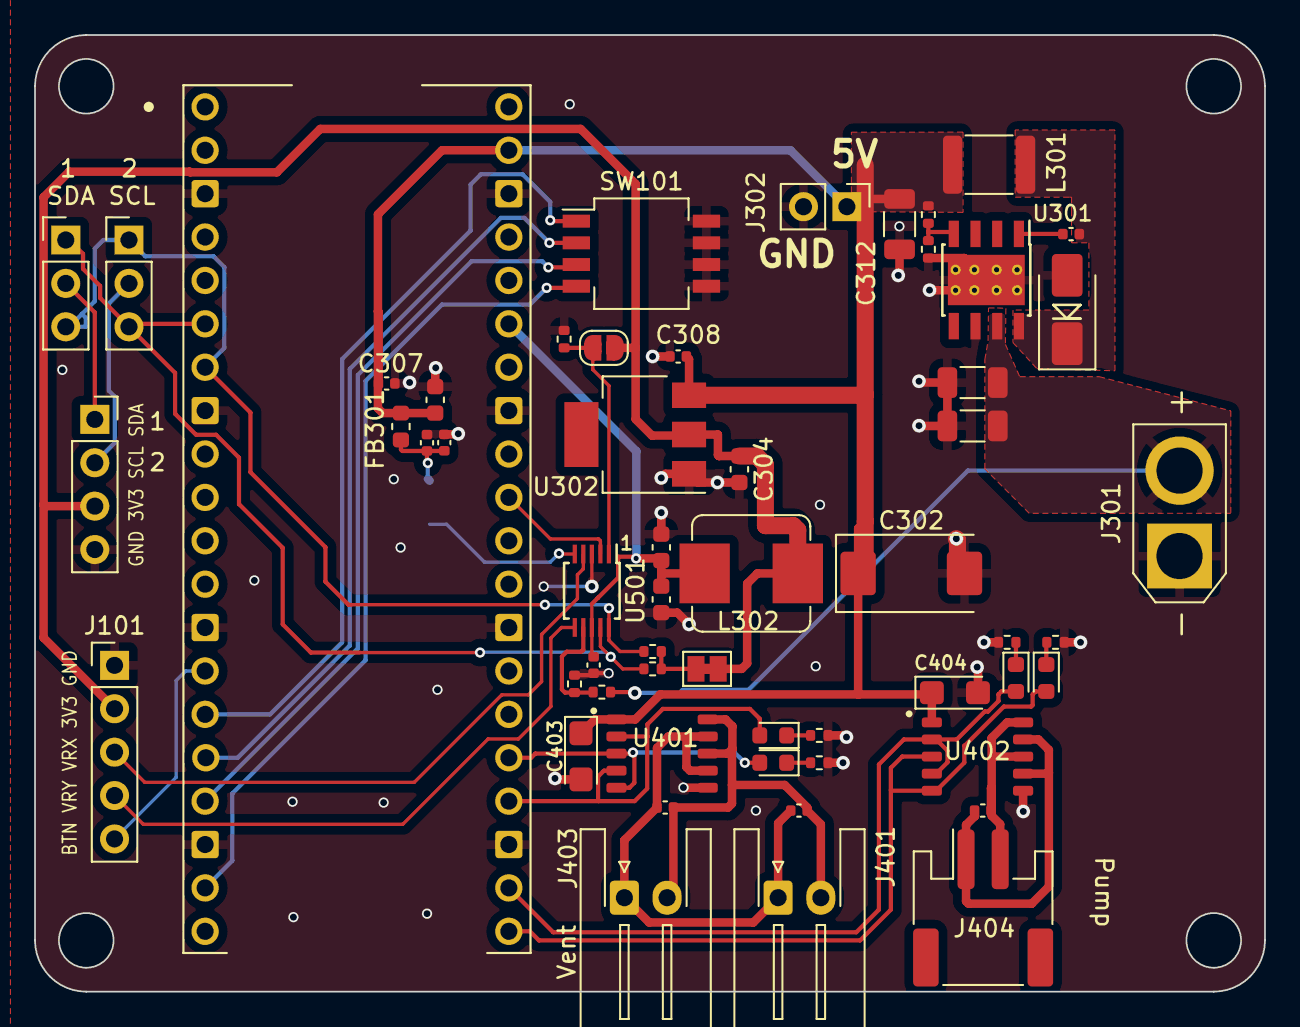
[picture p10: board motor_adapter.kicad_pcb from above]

Board: 2 copper layers, 72.0 x 56.0 mm, 57 parts (1 on the bottom side), 37 nets.

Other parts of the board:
C403, C404: 10uF; CP_EIA-3216-18_Kemet-A
J501: I2Cdisp1; PinSocket_1x04_P2.54mm_Vertical

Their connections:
+3.3V: J501.3; also elsewhere on the board
/display/vA: J501.1; also elsewhere on the board
/display/vB: J501.2; also elsewhere on the board
GND: C403.2, C404.2, J501.4; also elsewhere on the board

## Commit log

2023-08-15 Add first version to Gitrepository
    [adc_i2c.kicad_sch, display.kicad_sch, motor_adapter.kicad_pcb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]
2023-08-15 add 3D models
    [blowpipe_adapter_4.FCStd, pcb_box.FCStd, pcb_box_top.FCStd]
2023-08-15 remove version extension
    [blowpipe_adapter.FCStd]
